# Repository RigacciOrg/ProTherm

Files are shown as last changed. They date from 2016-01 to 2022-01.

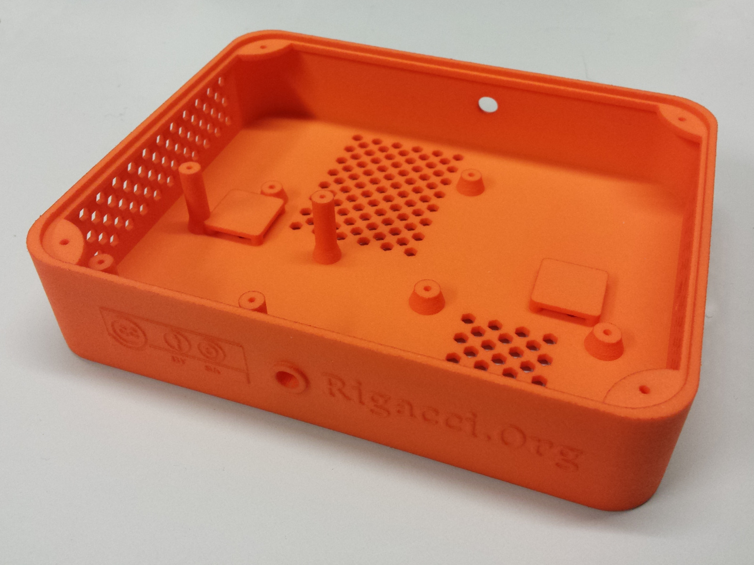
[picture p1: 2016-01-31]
case/images/protherm-3d-printed-case.jpg

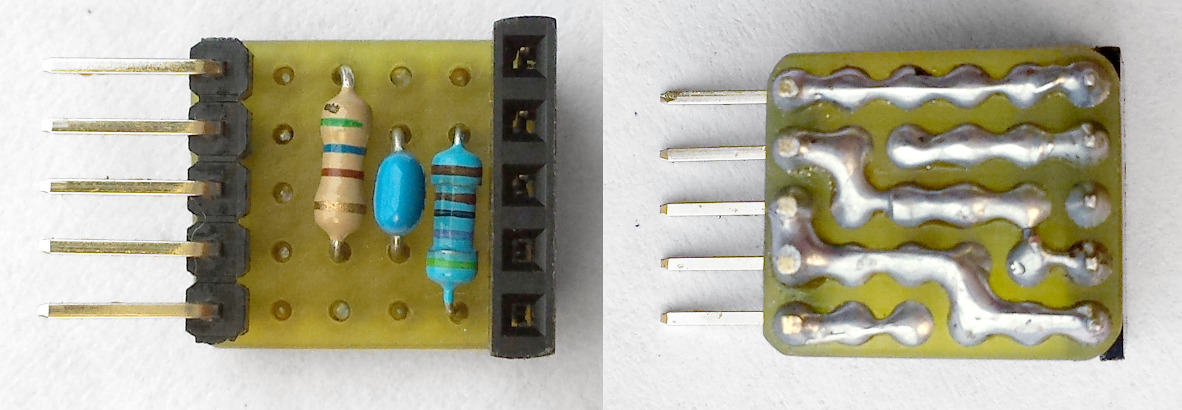
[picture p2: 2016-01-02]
docs/protherm-doughter.jpg

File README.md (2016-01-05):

# ProTherm, a programmable thermostat for the Raspberry Pi

http://www.rigacci.org/wiki/doku.php/doc/appunti/hardware/raspberrypi_thermostat

This is a do-it-yourself project to make a **programmable thermostat** with the **Raspberry Pi**, a credit-card sized computer costing about 35 €. I was frustrated by a low-cost thermostat which has only one daily program with just two temperatures. Time accuracy was of a quarter of an hour and temperature accuracy above one Celsius degree.

So I embarked on this project, whose main features are:

* Programmable with the **accuracy of the minute** and **tenths of a degree**.
* Can keep **several weekly programs**, plus MANUAL OFF and MANUAL ON modes.
* Show current status via an **LCD**.
* Just one **push button** to cycle through all the programs.
* Talks with the boiler with a **ON/OFF relay** (which controls the burner status).
* Remote operation and alerting messages via **Telegram Messenger chat**.
* Remote operation using a **web page**.
* Extensive graphing capabilities via **SNMP**.

This is the list of the hardware required, with their cost:

* **Raspberry Pi** model B with power supply (44 €)
* Dallas **DS18B20** temperature sensor (2 €)
* **Relay board** with two realys, but used just one (3.50 €)
* **Push button** (1 €)
* **LCD display** (Nokia 5110-3310) (5 €)
* Edimax **WiFi nano USB** adapter (10 €)

At the total of 65.50 € you must add a suitable case.

You can define several weekly programs and cycle among them pushing a button. There is a very basic web interface to manage the thermostat remotely, but the preferred way to talk to the thermostat is via Telegram Messenger chat.

## protherm

The Python daemon which polls the temperature sensor and sets the relay status (ON/OFF) accordingly to a temperature program.

## protherm-tbot

The Telegram Bot which send and receive messages to manage the thermostat remotely. It is written in Python using the telepot library.

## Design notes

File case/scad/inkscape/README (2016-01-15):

Come aggiungere una scritta in OpenSCAD

Per creare la scritta si usa Inkscape, occorre l'estensione
paths2openscad scaricabile da https://github.com/l0b0/paths2openscad

Copiare i file paths2openscad.inx e paths2openscad.py
in $HOME/.config/inkscape/extensions/

  * Disegnare una scritta, (size predefinita di Inkscape: 40 pixel)
  * Menu Path, Object to Path
  * Selezionare oggetto
    * Barra pulsanti, lock ratio, mm, width = 65 (impostare la misura)
    * Object, Align and Distribute, Relative to Page, Center
  * Menu Extensions, Generate from Path, Paths to OpenSCAD...
    Height 1 mm (sarà comunque possibile scalare dopo)
    Smoothing: 0.2 curve molto morbide

Utilizzare font che non hanno tratti troppo fini, secondo Shapeways.com
il tratto non deve essere inferiore a 0.2 mm.
Sempre secondo Shapeways.com le scritte devono essere in rilievo di 0.5
mm. Non conviene aumentare il rilievo, altrimenti vengono considerati
"wall" e viene quindi suggerito uno spessore di 1 mm.

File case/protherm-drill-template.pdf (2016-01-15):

A Programmable Thermostat with the Raspberry Pi https://www.rigacci.org/wiki/doku.php/doc/appunti/hardware/raspberrypi_thermostat

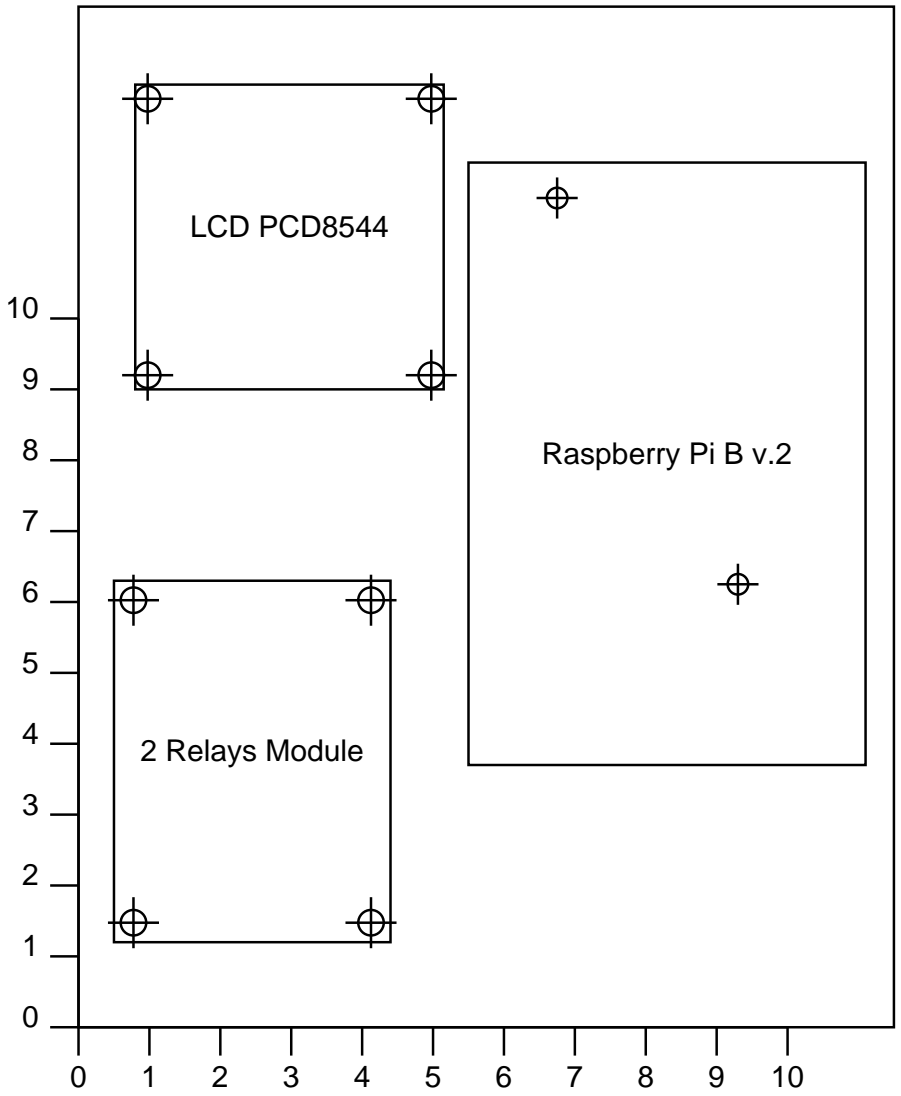
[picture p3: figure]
2 Relays Module; LCD PCD8544; Raspberry Pi B v.2

Check the length of the rules (they are cm) on printed paper! Tip: turn off auto-scaling and/or margins in print options.

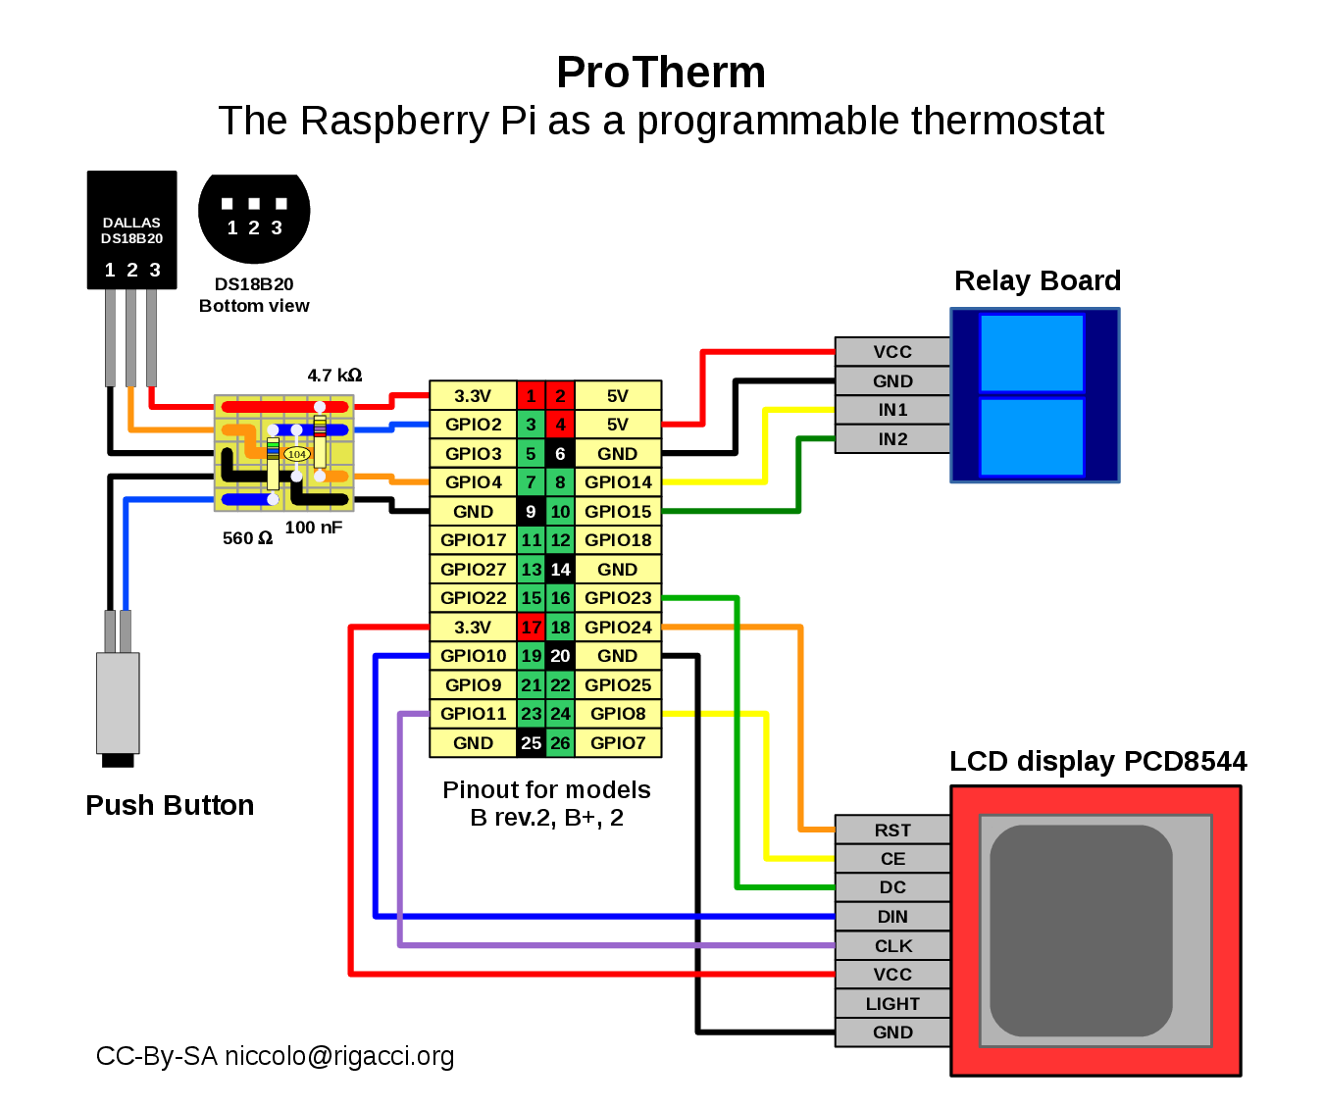
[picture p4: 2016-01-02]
docs/protherm-schematic.png

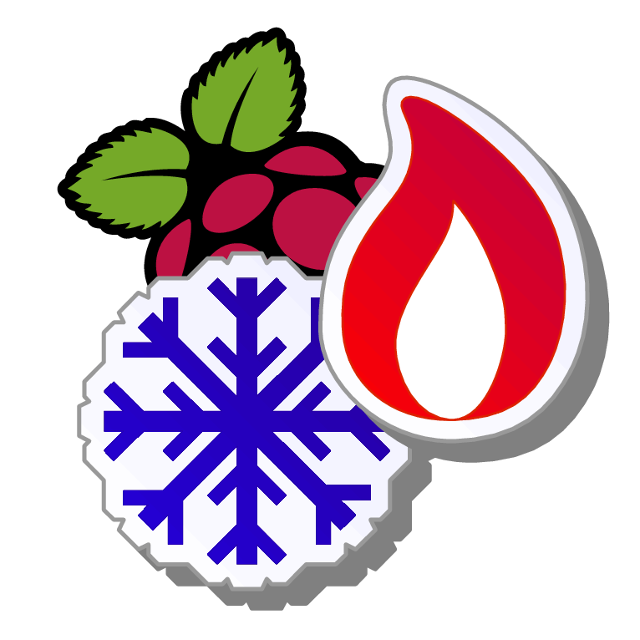
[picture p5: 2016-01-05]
docs/protherm_bot.png

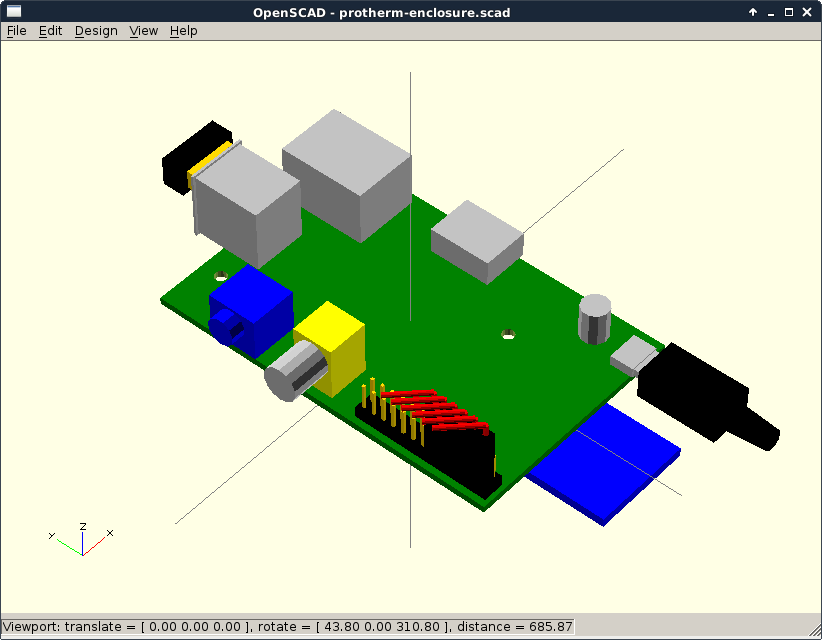
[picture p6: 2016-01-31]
case/images/openscad-raspberry-pi-model-b-v2.png

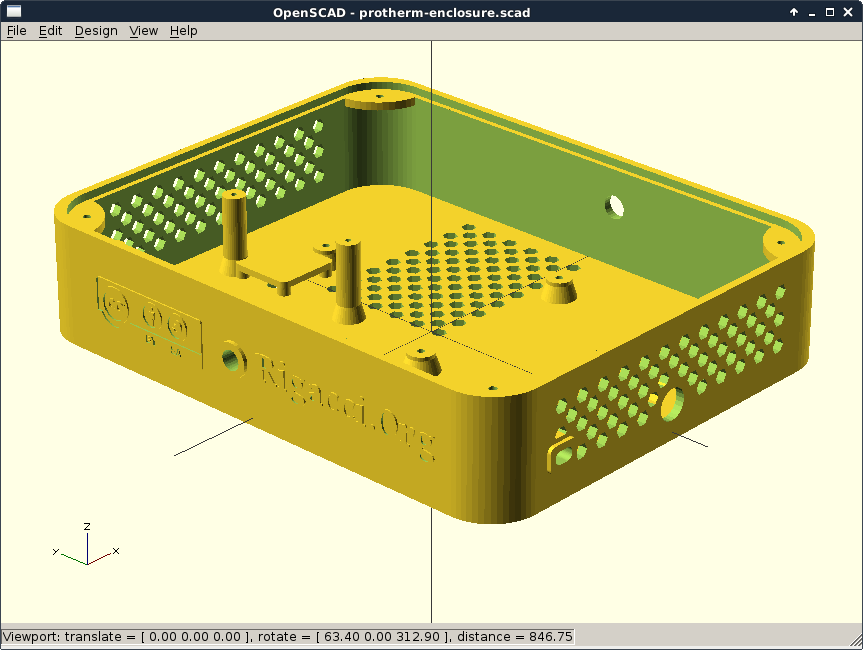
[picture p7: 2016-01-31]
case/images/protherm-openscad-screenshot.png

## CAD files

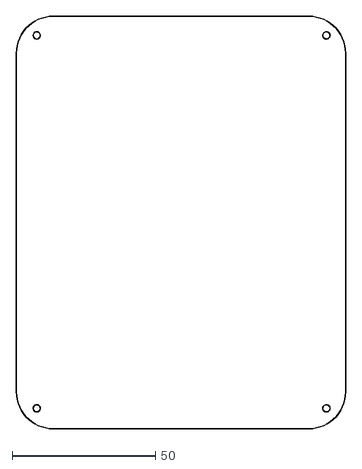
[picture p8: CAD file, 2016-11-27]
case/scad/protherm-2d-cover.dxf
114.8 x 143.8

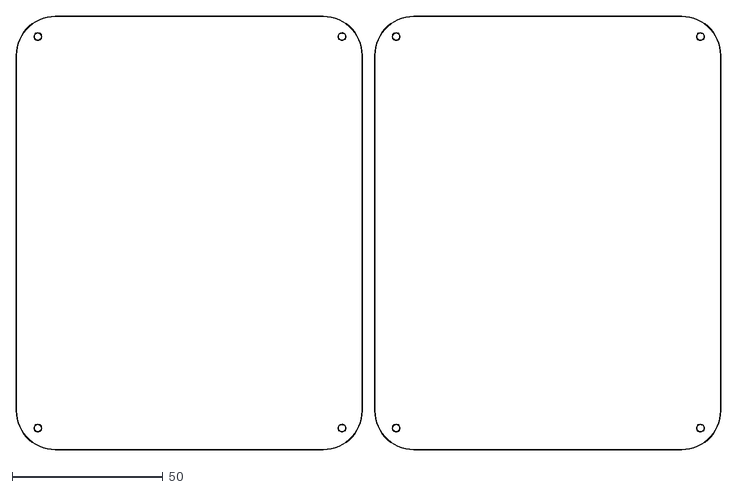
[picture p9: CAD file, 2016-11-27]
case/scad/protherm-2d-cover-double.dxf
233.8 x 143.8

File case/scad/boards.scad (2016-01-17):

//------------------------------------------------------------------------
// Two-relays module manufactured by SainSmart (or alike).
//------------------------------------------------------------------------
module board_2relays_sainsmart() {
    // Board with 3.0 mm holes.
    pcb_thick = 1.6;
    difference() {
        color("darkgreen") cube([39.0, 51.0, pcb_thick]);
        translate([2.75, 2.75, -overlap]) {
            translate([   0,    0, 0]) cylinder(r=1.5, h=(2 + overlap * 2), $fn=16);
            translate([33.5,    0, 0]) cylinder(r=1.5, h=(2 + overlap * 2), $fn=16);
            translate([   0, 45.5, 0]) cylinder(r=1.5, h=(2 + overlap * 2), $fn=16);
            translate([33.5, 45.5, 0]) cylinder(r=1.5, h=(2 + overlap * 2), $fn=16);
        }
    }
    translate([ 3.8, 12.2, pcb_thick])  color("blue") cube([15, 19, 16]);
    translate([20.2, 12.2, pcb_thick])  color("blue") cube([15, 19, 16]);
    translate([ 3.8,    4, pcb_thick])  color("blue") cube([15, 8, 10.2]);
    translate([20.2,    4, pcb_thick])  color("blue") cube([15, 8, 10.2]);
    translate([ 9, 46.5, 1.6]) pin_connector(4, 1);
    translate([ 9, 46.5, 1.6]) dupont_female(4, 1, [-1, 1, 0]);
    translate([24, 46.5, 1.6]) pin_connector(3, 1);
}

//------------------------------------------------------------------------
// Two-relays module manufactured by Keyes.
//------------------------------------------------------------------------
module board_2relays_keyes() {
    // Board with 3.6 mm holes.
    difference() {
        color("red") cube([45.5, 55, 2]);
        translate([3.5, 9, -overlap]) {
            translate([ 0,  0, 0]) cylinder(r=1.8, h=(2 + overlap * 2), $fn=16);
            translate([38,  0, 0]) cylinder(r=1.8, h=(2 + overlap * 2), $fn=16);
            translate([0,  40, 0]) cylinder(r=1.8, h=(2 + overlap * 2), $fn=16);
            translate([38, 40, 0]) cylinder(r=1.8, h=(2 + overlap * 2), $fn=16);
        }
    }
    translate([7.5, 15, 2])  color("blue") cube([15, 19, 16]);
    translate([23, 15, 2])   color("blue") cube([15, 19, 16]);
    translate([14.5, 48, 2]) pin_connector(6, 1);
}

//------------------------------------------------------------------------
// PCD8544 LCD module (from Nokia 5110/3310 phones), blue PCB.
// Pin on bottom, 3.2 mm holes spaced 34.5 x 41
//------------------------------------------------------------------------
module board_pcd8544_blue() {
    difference() {
        color("darkblue") cube([43, 45.5, 1.2]);
        translate([4.25, 2.25, -overlap]) {
            translate([ 0.0,  0, 0]) cylinder(r=1.6, h=(1.2 + overlap * 2), $fn=16);
            translate([34.5,  0, 0]) cylinder(r=1.6, h=(1.2 + overlap * 2), $fn=16);
            translate([ 0.0, 41, 0]) cylinder(r=1.6, h=(1.2 + overlap * 2), $fn=16);
            translate([34.5, 41, 0]) cylinder(r=1.6, h=(1.2 + overlap * 2), $fn=16);
        }
    }
    // Frame and LCD screen.
    difference() {
        translate([1.5, 6.0, 1.2])
            color("silver") cube([40, 34, 4]);
        translate([3.25, 7.5, 1.2 + 4 - 0.5])
            cube([36.5, 26, 0.6]);
    }
    translate([10.5, 2 + 2.54, 0])
        rotate(a=180, v=[1, 0, 0]) {
            pin_connector(8, 1);
            dupont_female(8, 1, [1, 1, 0]);
        }
}

//------------------------------------------------------------------------
// PCD8544 LCD module (from Nokia 5110/3310 phones), red PCB.
// Pin on top, 2.5 mm holes spaced 40 x 39
//------------------------------------------------------------------------
module board_pcd8544_red() {
    difference() {
        color("red") cube([43.5, 43.0, 1.2]);
        translate([1.75, 2.0, -overlap]) {
            translate([ 0,  0, 0]) cylinder(r=1.25, h=(1.2 + overlap * 2), $fn=16);
            translate([40,  0, 0]) cylinder(r=1.25, h=(1.2 + overlap * 2), $fn=16);
            translate([ 0, 39, 0]) cylinder(r=1.25, h=(1.2 + overlap * 2), $fn=16);
            translate([40, 39, 0]) cylinder(r=1.25, h=(1.2 + overlap * 2), $fn=16);
        }
    }
    // Frame and LCD screen.
    difference() {
        translate([1.75, 5, 1.2])
            color("silver") cube([40, 34, 4]);
        translate([3.5, 7, 1.2 + 4 - 0.5])
            cube([36.5, 26, 0.6]);
    }
    translate([11.5, 42.5, 0])
        rotate(a=180, v=[1, 0, 0]) {
            pin_connector(8, 1);
            dupont_female(8, 1, [-1, 1, 0]);
        }
}

//------------------------------------------------------------------------
// Sub-models for the Raspberry Pi Model B v.2
//------------------------------------------------------------------------
module video_rca() {
    x = 10; y = 9.8; z = 13;
    d = 8.3; h = 9.5;
    color("yellow") cube([x, y, z]);
    translate([-h, y / 2, (d / 2) + 4])
        rotate(a=90, v=[0, 1, 0])
            color("silver") cylinder(r=(d / 2), h=h);
}
module audio_jack() {
    x = 11.4; y = 12; z = 10.2;
    d = 6.7; h = 3.4;
    color("blue") cube([x, y, z]);
    translate([-h, y / 2, (d / 2) + 3])
        rotate(a=90, v=[0, 1, 0])
            color("blue") cylinder(r=(d / 2), h=h);
}
module ethernet_connector(x, y, z) {
    color("silver") cube([x, y, z]);
}
module usb_connector(x, y, z) {
    f = 0.6; // Flange
    color("silver") cube([x, y, z]);
    translate([-f, y - f, -f])
        color("silver") cube([x + f * 2, f, z + f * 2]);
}
module hdmi_connector(x, y, z) {
    color("silver") cube([x, y, z]);
}
module microusb_connector(x, y, z) {
    color("silver") cube([x, y, z]);
}
module capacitor(d, h) {
    color("silver") cylinder(r=(d / 2), h=h);
}

//------------------------------------------------------------------------
// Raspberry Pi Model B v.2
//------------------------------------------------------------------------
module board_raspberrypi_model_b_v2() {

    x  = 56;     y = 85;    z =  1.6;	// Official PCB size
    ex = 15.40; ey = 21.8; ez = 13.0;	// Official Ethernet offset
    ex = 16.00; ey = 21.3; ez = 13.5;	// Measured Ethernet offset
    ux = 13.25; uy = 17.2; uz = 15.3;	// Official USB connector offset
    hx = 11.40; hy = 15.1; hz = 6.15;	// Official HDMI connector offset
    mx =  7.60; my =  5.6; mz = 2.40;	// Official micro USB power connector

    // The origin is the lower face of PCB.
    translate([0, 0, z]) {
        translate([x - 2 - ex, y - ey + 1, 0])     ethernet_connector(ex, ey, ez);
        translate([1.5, 1.0, 0])                   pin_connector(2, 13);
        translate([1.5, 1.0, 0])                   dupont_female(1, 6, [-1, -1, 0]);
        translate([2.1, 40.6, 0])                  video_rca();
        translate([0, 59.0, 0])                    audio_jack();
        translate([18.8, 85 - uy + 7.7, 0])        usb_connector(ux, uy, uz);
        translate([x - hx + 1.2, 37.5, 0])         hdmi_connector(hx, hy, hz);
        translate([x - mx - 3.6, -0.5, 0])         microusb_connector(mx, my, mz);
        translate([14, -18, -4.4])                 sd_card();     // Inserted
        //translate([14, -32, -4.4])               sd_card();     // Extracted
        translate([x - mx - 3.6 + 0.375, -3, 0.3]) microusb_plug();
        translate([49.35, 12.75])                  capacitor(6.5, 8);
        translate([18.8 + 0.625, 83, 10.4])        wifi_usb_edimax();
        translate([0, 0, -z]) {
            difference() {
                color("green") cube([x, y, z]);
                translate([(x - 18), 25.5, -overcut]) cylinder(r=(2.9 / 2), h=(z + overcut * 2), $fn=16);
                translate([12.5, (y - 5), -overcut])  cylinder(r=(2.9 / 2), h=(z + overcut * 2), $fn=16);
            }
        }
    }
}

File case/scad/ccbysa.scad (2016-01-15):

// Module names are of the form poly_<inkscape-path-id>().  As a result,
// you can associate a polygon in this OpenSCAD program with the corresponding
// SVG element in the Inkscape document by looking for the XML element with
// the attribute id="inkscape-path-id".

// fudge value is used to ensure that subtracted solids are a tad taller
// in the z dimension than the polygon being subtracted from.  This helps
// keep the resulting .stl file manifold.
fudge = 0.1;

module poly_path4691(h)
{
  scale([25.4/90, -25.4/90, 1]) union()
  {
    linear_extrude(height=h)
      polygon([[1.008347,-10.221613],[0.442363,-9.982965],[0.202102,-9.415368],[0.202102,-4.398731],[1.590636,-4.398731],[1.590636,1.558526],[5.397905,1.558526],[5.397905,-4.398731],[6.786438,-4.398731],[6.786438,-9.415368],[6.546709,-9.982965],[5.980193,-10.221613],[1.008347,-10.221613]]);
  }
}

module poly_path4580(h)
{
  scale([25.4/90, -25.4/90, 1]) union()
  {
    linear_extrude(height=h)
      polygon([[-1.768720,16.294826],[-1.768720,18.220856],[-0.111438,18.220856],[0.291685,18.176136],[0.650016,18.041834],[0.918765,17.773085],[1.008347,17.325171],[0.694808,16.518926],[-0.111438,16.294969],[-1.768720,16.294969]]);
  }
}

module poly_path4687(h)
{
  scale([25.4/90, -25.4/90, 1]) union()
  {
    linear_extrude(height=h)
      polygon([[-36.168517,-6.638301],[-38.077885,-6.291257],[-39.617455,-5.249767],[-40.627412,-3.634410],[-40.961197,-1.532081],[-40.622042,0.630090],[-39.617455,2.275188],[-38.068031,3.289445],[-36.078934,3.618930],[-34.734856,3.460671],[-33.570437,2.984147],[-32.585272,2.186736],[-31.778960,1.065820],[-33.839364,-0.009173],[-34.631097,1.067075],[-35.854977,1.424152],[-36.821341,1.238379],[-37.506526,0.682406],[-37.914632,-0.241753],[-38.049756,-1.532081],[-37.914632,-2.821805],[-37.506526,-3.746030],[-36.821341,-4.302340],[-35.854977,-4.488314],[-34.815643,-4.153991],[-34.063321,-3.144571],[-31.823751,-4.264357],[-32.586672,-5.311927],[-33.565599,-6.052788],[-34.759794,-6.492919],[-36.168517,-6.638301]]);
  }
}

module poly_path4703(h)
{
  scale([25.4/90, -25.4/90, 1]) union()
  {
    difference()
    {
       linear_extrude(height=h)
         polygon([[-41.118508,-18.050935],[-44.399794,-17.751964],[-47.420664,-16.854288],[-50.179501,-15.356766],[-52.674690,-13.258255],[-54.794712,-10.664520],[-56.306019,-7.845841],[-57.211029,-4.799533],[-57.512162,-1.522908],[-57.211029,1.754378],[-56.306019,4.798055],[-54.794712,7.603889],[-52.674690,10.167649],[-50.133539,12.303135],[-47.359384,13.828898],[-44.353836,14.744602],[-41.118508,15.049911],[-37.843898,14.741433],[-34.798799,13.816715],[-31.979718,12.276831],[-29.383160,10.122857],[-27.330090,7.640271],[-25.859869,4.869184],[-24.975518,1.813492],[-24.680063,-1.522908],[-24.982058,-4.861614],[-25.884773,-7.928616],[-27.383303,-10.726600],[-29.472743,-13.258255],[-31.985563,-15.356766],[-34.760816,-16.854288],[-37.803474,-17.751964],[-41.118508,-18.050935]]);
       translate([0, 0, -fudge])
         linear_extrude(height=h+2*fudge)
           polygon([[-41.073788,-15.094703],[-38.385343,-14.842292],[-35.909345,-14.089405],[-33.641624,-12.842558],[-31.578011,-11.108268],[-29.857976,-9.030462],[-28.625720,-6.744510],[-27.884198,-4.244097],[-27.636367,-1.522908],[-27.876046,1.213713],[-28.596516,3.710878],[-29.799927,5.965095],[-31.488428,7.972870],[-33.614206,9.750786],[-35.920985,11.025135],[-38.407826,11.792356],[-41.073788,12.048887],[-43.733412,11.795323],[-46.202225,11.036781],[-48.480764,9.776485],[-50.569566,8.017661],[-52.314094,5.914201],[-53.559777,3.620400],[-54.306946,1.140087],[-54.555929,-1.522908],[-54.303977,-4.184637],[-53.548122,-6.667648],[-52.288364,-8.974629],[-50.524703,-11.108268],[-48.485630,-12.848000],[-46.231357,-14.094242],[-43.761010,-14.844106],[-41.073717,-15.094703]]);
    }
  }
}

module poly_path4705(h)
{
  scale([25.4/90, -25.4/90, 1]) union()
  {
    difference()
    {
       linear_extrude(height=h)
         polygon([[33.369595,-18.633224],[30.937566,-18.413712],[28.702863,-17.752983],[26.662737,-16.647744],[24.814437,-15.094703],[23.234701,-13.166399],[22.100078,-11.065089],[21.415610,-8.795005],[21.186334,-6.360379],[21.415610,-3.933906],[22.100078,-1.684873],[23.234701,0.387591],[24.814437,2.284362],[26.697406,3.868936],[28.749088,5.003021],[30.972234,5.684802],[33.369595,5.912465],[35.804221,5.680625],[38.072155,4.988150],[40.172390,3.839609],[42.103919,2.239570],[43.619985,0.404623],[44.696983,-1.638470],[45.339683,-3.892530],[45.552857,-6.360379],[45.331935,-8.840356],[44.668854,-11.125826],[43.563144,-13.212154],[42.014336,-15.094703],[40.149614,-16.647744],[38.089713,-17.752983],[35.830939,-18.413712],[33.369595,-18.633224]]);
       translate([0, 0, -fudge])
         linear_extrude(height=h+2*fudge)
           polygon([[33.414315,-16.438445],[35.408230,-16.252471],[37.242715,-15.696162],[38.921063,-14.771936],[40.446565,-13.482212],[41.724453,-11.943930],[42.633819,-10.243256],[43.177419,-8.381603],[43.358007,-6.360379],[43.179177,-4.333199],[42.642240,-2.484131],[41.746524,-0.815125],[40.491357,0.671871],[38.919358,1.985525],[37.219972,2.923266],[35.387018,3.485566],[33.414315,3.672895],[31.436369,3.482744],[29.593603,2.915741],[27.891932,1.977059],[26.337273,0.671871],[25.043317,-0.881439],[24.119561,-2.568518],[23.565604,-4.393466],[23.381041,-6.360379],[23.569579,-8.335647],[24.133895,-10.181982],[25.072039,-11.897974],[26.382065,-13.482212],[27.897280,-14.773145],[29.576767,-15.697237],[31.416966,-16.252874],[33.414315,-16.438445]]);
    }
  }
}

module poly_path4707(h)
{
  scale([25.4/90, -25.4/90, 1]) union()
  {
    difference()
    {
       linear_extrude(height=h)
         polygon([[3.493729,-18.633224],[1.061901,-18.413712],[-1.172465,-17.752983],[-3.212524,-16.647744],[-5.061429,-15.094703],[-6.641165,-13.166802],[-7.775788,-11.065089],[-8.460256,-8.794602],[-8.689532,-6.360379],[-8.460256,-3.934510],[-7.775788,-1.685411],[-6.641165,0.387390],[-5.061429,2.284362],[-3.178662,3.868936],[-1.127315,5.003021],[1.095764,5.684802],[3.493729,5.912465],[5.928557,5.680826],[8.196827,4.988687],[10.297129,3.840213],[12.228053,2.239570],[13.752932,0.404825],[14.845125,-1.637932],[15.502215,-3.891925],[15.721782,-6.360379],[15.500860,-8.840961],[14.837779,-11.126364],[13.732070,-13.212355],[12.183262,-15.094703],[10.311541,-16.647744],[8.236243,-17.752983],[5.962072,-18.413712],[3.493729,-18.633224]]);
       translate([0, 0, -fudge])
         linear_extrude(height=h+2*fudge)
           polygon([[3.538449,-16.438445],[5.532568,-16.252471],[7.367392,-15.696162],[9.045808,-14.771936],[10.570699,-13.482212],[11.856795,-11.943728],[12.781424,-10.242719],[13.339749,-8.380998],[13.526932,-6.360379],[13.348102,-4.333199],[12.811165,-2.484131],[11.915449,-0.815125],[10.660282,0.671871],[9.081285,1.986129],[7.366502,2.923804],[5.518151,3.485768],[3.538449,3.672895],[1.567502,3.482946],[-0.259867,2.916279],[-1.946141,1.977664],[-3.493801,0.671871],[-4.795361,-0.880633],[-5.734446,-2.567443],[-6.303465,-4.392659],[-6.494825,-6.360379],[-6.306287,-8.335042],[-5.741971,-10.181444],[-4.803826,-11.897772],[-3.493801,-13.482212],[-1.977383,-14.771936],[-0.298029,-15.696162],[1.541501,-16.252471],[3.538449,-16.438445]]);
    }
  }
}

module poly_path4675(h)
{
  scale([25.4/90, -25.4/90, 1]) union()
  {
    linear_extrude(height=h)
      polygon([[35.408145,14.144838],[34.512317,16.697948],[36.303973,16.697948],[35.408145,14.144838]]);
  }
}

module poly_path4695(h)
{
  scale([25.4/90, -25.4/90, 1]) union()
  {
    linear_extrude(height=h)
      polygon([[3.516666,-14.297631],[2.853434,-14.164914],[2.312489,-13.801880],[1.948114,-13.261203],[1.814593,-12.595558],[1.948114,-11.922914],[2.312489,-11.366840],[2.853434,-10.988408],[3.516666,-10.848693],[4.179282,-10.988408],[4.720295,-11.366840],[5.085013,-11.922914],[5.218739,-12.595558],[5.085013,-13.261203],[4.720295,-13.801880],[4.179282,-14.164914],[3.516666,-14.297631]]);
  }
}

module poly_path4689(h)
{
  scale([25.4/90, -25.4/90, 1]) union()
  {
    linear_extrude(height=h)
      polygon([[-45.664295,-6.638301],[-47.558075,-6.291257],[-49.113233,-5.249767],[-50.128564,-3.634410],[-50.456975,-1.532081],[-50.118889,0.630090],[-49.113233,2.275188],[-47.564346,3.289445],[-45.574712,3.618930],[-44.229626,3.460671],[-43.065677,2.984147],[-42.081251,2.186736],[-41.274737,1.065820],[-43.290350,-0.009173],[-44.115772,1.067075],[-45.350755,1.424152],[-46.298032,1.238379],[-46.969163,0.682406],[-47.368587,-0.241753],[-47.500742,-1.532081],[-47.368587,-2.821805],[-46.969163,-3.746030],[-46.298032,-4.302340],[-45.350755,-4.488314],[-44.256949,-4.153991],[-43.469516,-3.144571],[-41.319529,-4.264357],[-42.083054,-5.311927],[-43.060839,-6.052788],[-44.254160,-6.492919],[-45.664295,-6.638301]]);
  }
}
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

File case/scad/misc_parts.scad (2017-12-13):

//------------------------------------------------------------------------
// Rocker switch.
//------------------------------------------------------------------------
module rocker_switch() {
    x1 = 19.0; y1 = 12.0; z1 = 10.5;
    x2 = 21.5; y2 = 15.0; z2 =  2.0;
    x3 = 0.75; y3 =  4.9; z3 =  8.5;
    x4 = 15;   y4 =  10;  z4 =  4;
    step = 6.8;
    pin = 3;
    union() {
        color("brown") translate([-(x1 / 2), -(y1 / 2), -z1]) cube([x1, y1, z1]);
        color("brown") translate([-(x2 / 2), -(y2 / 2), 0])   cube([x2, y2, z2]);
        color("brown") rotate(a=10, v=[0, 1, 0]) translate([-(x4 / 2), -(y4 / 2), 0]) cube([x4, y4, z4]);
        for(i = [0 : (pin -1)]) {
            translate([-(((pin - 1) * step / 2)) + (step * i) - (x3 / 2), -(y3 / 2), -(z1 + z3)])
                color("silver") cube([x3, y3, z3]);
        }
    }
}

//------------------------------------------------------------------------
// Coaxial power plug socket, 2.1 mm.
//------------------------------------------------------------------------
module coax_power_socket() {
    r1 = 5.00; h1 = 4;
    r2 = 4.00; h2 = 8.0;
    r3 = 2.75; h3 = 10;  // Hole
    r4 = 6.50; h4 = 2.2; // Bolt
    r5 = 1.05; h5 = 3.0; // Center pin
    x1 = 2.2; y1 = 0.3; z1 = 5;
    step = 4.5;
    color([0.15, 0.15, 0.15]) difference() {
        union() {
            cylinder(r=r1, h=h1, $fn=18);
            translate([0, 0, -h2]) cylinder(r=r2, h=h2, $fn=18);
        }
        translate([0, 0, -h3 + h1 ]) cylinder(r=r3, h=(h3 + overcut), $fn=18);
    }
    color("silver") cylinder(r=r5, h=h5, $fn=18);
    translate([0, 0, -(h4 + 2)]) color("gray") cylinder(r=r4, h=h4, $fn=6);
    translate([-(x1 / 2), (step - y1) / 2, -(h2 + z1)])  color("gold") cube([x1, y1, z1]);
    translate([-(x1 / 2), -(step + y1) / 2, -(h2 + z1)]) color("gold") cube([x1, y1, z1]);
}

//------------------------------------------------------------------------
// Mini push button.
//------------------------------------------------------------------------
module push_button() {
    $fn = 24;
    r1 = 2.0; h1 = 4;
    r2 = 3.1; h2 = 6.5;
    r3 = 5.0; h3 = 8.0;
    r4 = 4.5; h4 = 1.8;  // Nut.
    x1 = 2.5; y1 = 0.3; z1 = 6;
    step = 5;
    translate([0, 0, h2])  color("black")  cylinder(r=r1, h=h1);
    translate([0, 0, 0])   color("silver") cylinder(r=r2, h=h2);
    translate([0, 0, -h3]) color("gray")   cylinder(r=r3, h=h3);
    translate([0, 0, 2])   color("gray")   cylinder(r=r4, h=h4, $fn=6);
    translate([-(x1 / 2), (step - y1) / 2, -(h3 + z1)])  color("gold") cube([x1, y1, z1]);
    translate([-(x1 / 2), -(step + y1) / 2, -(h3 + z1)]) color("gold") cube([x1, y1, z1]);
}

//------------------------------------------------------------------------
// Matrix of 2.54 mm dupont female connectors.
//------------------------------------------------------------------------
module dupont_female(cols, rows, wire_v) {
    w = 2.54; h = 14;
    wire_d = 1.2;
    z = 2.74; // Stay 0.2 mm above the pin connector.
    for(x = [0 : (cols -1)]) {
        for(y = [0 : (rows  - 1)]) {
            translate([w * x, w * y, z]) {
                color("black") cube ([w, w, h]);
                translate([w / 2, w / 2, h]) {
                    color("red") cylinder(r=wire_d / 2, h=2.5);
                        translate([0, 0, 2.5]) rotate(a=90, v=wire_v)
                            color("red") cylinder(r=wire_d / 2, h=10, $fn=12);
                }
            }
        }
    }
}

//------------------------------------------------------------------------
// Matrix of 2.54 mm pins.
//------------------------------------------------------------------------
module pin_connector(cols, rows) {
    w = 2.54; h = 2.54; p = 0.64;
    for(x = [0 : (cols -1)]) {
        for(y = [0 : (rows  - 1)]) {
            translate([w * x, w * y, 0]) {
                union() {
                    color("black") cube([w, w, h]);
                    color("gold")  translate([(w - p) / 2, (w - p) / 2, -3]) cube([p, p, 11.54]);
                }
            }
        }
    }
}

//------------------------------------------------------------------------
// Secure Digital Memory Card 24x32 mm.
//------------------------------------------------------------------------
module sd_card() {
    color("blue")
        linear_extrude(height=2.1)
            polygon([[0, 0], [24, 0], [24, 32], [4.5, 32], [0, (32 - 4.5)]]);
}

//------------------------------------------------------------------------
// Generic Micro-USB connector.
//------------------------------------------------------------------------
module microusb_plug() {
    x1 = 6.85; y1 = 6.70; z1 = 1.80;
    x2 = 10.5; y2 = 19;   z2 = 7;
    r1 = 3.2;  r2 = 2.4; h = 10;
    color("silver") cube([x1, y1, z1]);
    color("black") translate([-(x2 - x1) / 2, -19, -(z2 - z1) / 2]) cube([x2, y2, z2]);
    color("black") translate([x1/2, -y2, z1/2]) rotate(a=90, v=[1, 0, 0]) cylinder(r1=r1, r2=r2, h=h);
}

//------------------------------------------------------------------------
// Nano WiFi USB dongle by Edimax (EW-7811UN).
//------------------------------------------------------------------------
module wifi_usb_edimax() {
    x1 = 12.0; y1 = 12.0; z1 = 4.5;
    x2 = 15.0; y2 =  5.5; z2 = 7.0;
    color("gold") cube([x1, y1, z1]);
    translate([(x1 - x2) / 2, y1, (z1 - z2) / 2])
        color("black") cube([x2, y2, z2]);
}

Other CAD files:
case/scad/protherm-enclosure.scad
case/scad/RigacciOrg.scad
case/scad/rounded_cube.scad

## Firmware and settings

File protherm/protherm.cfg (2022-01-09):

[protherm]

# Temperature sensor device ID.
TEMP_SENSOR = /sys/bus/w1/devices/28-0000067bc546/w1_slave

# Raspberry Pi hardware SPI config for Nokia LCD.
LCD_ENABLED  = True
LCD_CONTRAST = 55
LCD_DC = 23
LCD_RST = 24
LCD_SPI_PORT = 0
LCD_SPI_DEVICE = 0

# GPIO connected to button.
BUTTON1_GPIO = 2
BUTTON1_ENABLED = True
# Button connects the GPIO to 3.3 v (active high) or to ground.
BUTTON1_ACTIVE_HIGH = False

# GPIO connected to switch relays.
SWITCH1_GPIO = 14
SWITCH2_GPIO = 15
# Relay module board uses "active high" signaling.
RELAY_ACTIVE_HIGH = False

# Networking.
WIRED_IFACE = eth0
WIFI_IFACE = wlan0
# Link quality reported by iwconfig, usually is 100-based.
WIFI_QUALITY_SCALE = 100

# From logging module: NOTSET, DEBUG, INFO, WARNING, ERROR, CRITICAL
LOG_LEVEL = INFO

# Filename for file logging, False for syslog.
LOG_TO_FILE  = False
#LOG_TO_FILE = /var/log/protherm.log

# Log format suitable for systemd and journalctl.
LOG_FORMAT = %(levelname)s %(message)s
## Log format suitable for syslog (include program name).
#LOG_FORMAT = %(module)s: %(levelname)s %(message)s
## Log format suitable for file or stdout (include timestamp).
#LOG_FORMAT = %(asctime)s %(levelname)s %(message)s

# Use Celsius or Fahrenheit (C or F).
DEGREES_UNIT = C

# Default temperature, if no program is defined.
DEFAULT_TEMPERATURE = 10.0

# Programmed temperature hysteresis for changing switch state.
TEMP_HYSTERESIS = 0.2

# Use the old Adafruit_Nokia_LCD instead of adafruit_pcd8544.
OLD_LCD_LIBRARY = True

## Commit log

2015-12-21 Added example configuration files and start/stop rc scripts.
    [protherm-tbot.cfg, protherm.cfg]
2015-12-22 Added examples of programmed temperature files.
2015-12-24 New configuration option: ENABLE_PASSWORD.
    [protherm.cfg]
2015-12-29 Added TEMP_HYSTERESIS to configuration options.
    [protherm.cfg]
2015-12-29 Added temperature hysteresis logic and enable password stub code.
2015-12-30 Added schematic diagram (LibreOffice and PNG).
2016-01-01 Changed default GPIOs for relays in example configuration file.
    [protherm.cfg]
2016-01-01 Added check for bad CRC from temperature sensor.
2016-01-01 Changed economy temperature in example program PROG2.
2016-01-02 Updated wiring diagram: use GPIO2 for button instead of GPIO18.
2016-01-02 Added photo of small doughter bord for button and DS18B20.
2016-01-04 Emit error messages if timer functions execute too slow.
2016-01-04 Changed default GPIO button to 2 instead of 18.
2016-01-04 Minor fixes to timer handlers and better log message.
2016-01-05 Added some pictures: LCD sample, icons vector and bitmap.
2016-01-11 Changed default GPIO for push button from 18 to 2.
    [protherm.cfg]
2016-01-12 Check if SPI device is writable, otherwise disable LCD.
2016-01-13 The first button press (after 5 minutes of button inactivity) is used to reset the LCD instead of cycling the thermostat program.
2016-01-15 Added an OpenSCAD model of a 3D printable enclosure.
    [RigacciOrg.scad, boards.scad, ccbysa.scad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]
2016-01-17 LCD reset and clear on exit. Fixed race condition in timer cancelling on exit.
2016-01-17 Fixed some comments.
    [boards.scad]
2016-01-17 New shape for screw_hole_cap() module.
    [protherm-enclosure.scad]
2016-01-17 Changed all the screw holes to accept 2.2 mm diameter screws.
    [protherm-enclosure.scad]
2016-01-18 Fixed diameter of some holes.
    [misc_parts.scad, protherm-enclosure.scad]
2016-01-31 Added photos of the 3D printed case and OpenSCAD screenshots.
2016-02-01 Added a threading semaphore to access the LCD. Fixes LCD going blank problem?
2016-07-14 LCD SPI speed restored to 4 MHz.
2016-10-20 Fixed type in comment.
    [protherm-enclosure.scad]
2016-11-27 Added 2D model for lasercut case cover
    [protherm-2d-cover-double.dxf, protherm-2d-cover.dxf, protherm-enclosure.scad]
2016-12-06 Added comment about laser cutting and kerf width.
    [protherm-enclosure.scad]
2017-12-13 Renamed power jack socket module
    [misc_parts.scad, protherm-enclosure.scad]
2020-04-30 Fixed main loop bug and added exception for PID file writing error
2020-04-30 Fixed main loop bug and added exception to catch PID file creation error
2020-04-30 Added README for lasercut writing
2022-01-09 Refactoring: Python 3 and new Python library for the PCD8544 display
    [protherm.cfg]
2022-01-09 Send signal to ProTherm process via sysvinit/PID or via systemd service
2022-01-13 Systemd and undev rules to start protherm after spidev device
